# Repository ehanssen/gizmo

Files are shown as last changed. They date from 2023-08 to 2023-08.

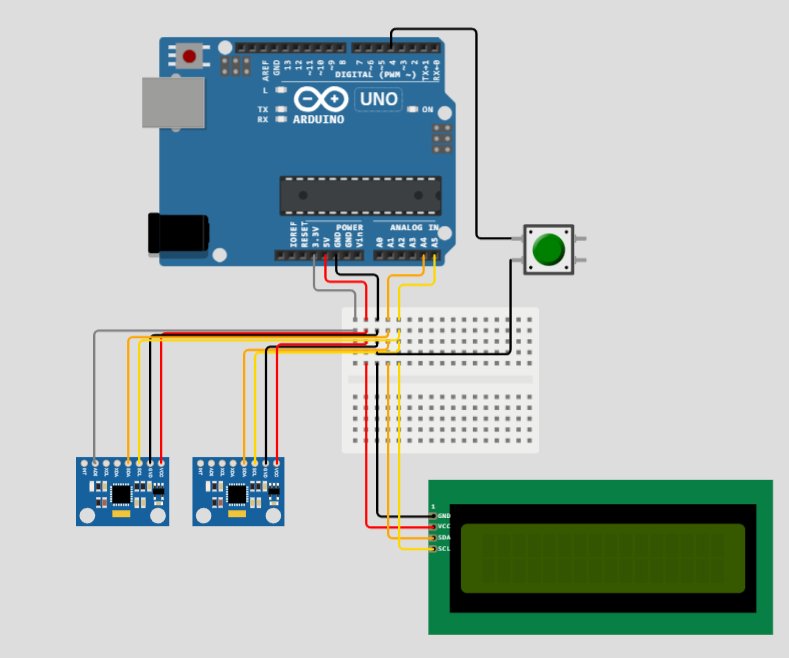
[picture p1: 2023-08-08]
wiring/wiring.jpg

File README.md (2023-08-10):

# Gizmo
A little tool to help read angles from ultramicrotomes. Works with https://github.com/automated-ultramicrotomy/crosshair

# Manual
- sample and knife at 0 degres
- start Gizmo and wait for a few seconds until values show on the LCD (usually 15-20sec)
- Press the button which will reset all values to 0 degres (+/- a small value)
- Set up CrossHair and record value
- Rotate the samples and knife by the offsets given by CrossHair
- All ROT, TLT and KNF drift a little overtime so make sure you add the offset more than the pure values
  (eg initial ROT was 4 degres, CrossHair ask for 6 degres but the original value of Gizmo slowly drifted to 4.6 degres while doing alignement and crosshair set up so set 6.6 degres) 

# Cite
Eric Hanssen and Phil Francis, Ian Holmes Imaging Centre, Bio21 Institute, the University of Melbourne.
[doi:10.5281/zenodo.8223274](https://doi.org/10.5281/zenodo.8223274)

# Note
Depending on your MPU6050 (and mainly where you get them from) you will likely have different readings. It is worth purchasing a few sensors and trying them all. Out of 6 sensors we origialy bought 2 where not working as they should and one was a not reliable.

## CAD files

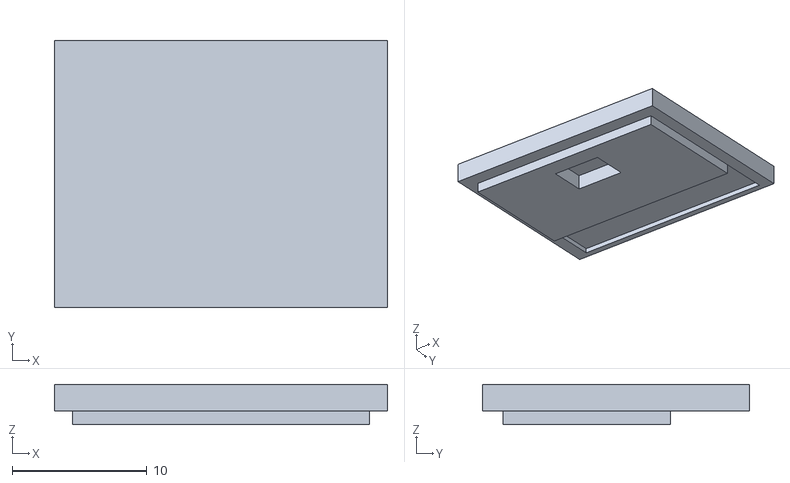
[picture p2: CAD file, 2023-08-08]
stl_files/top_MPU6050.stl
24.7 x 19.8 x 3.00

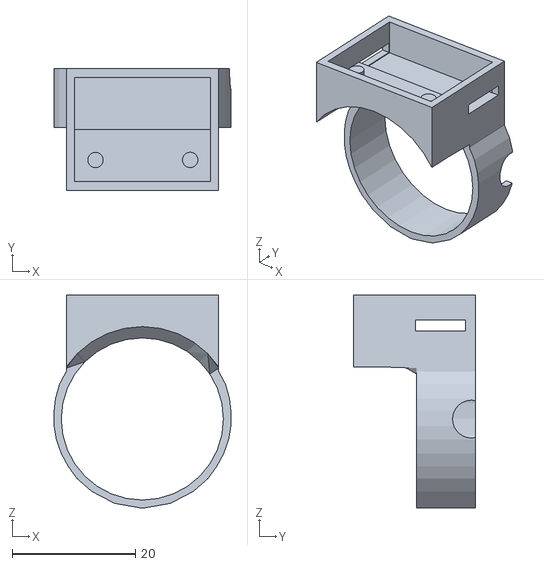
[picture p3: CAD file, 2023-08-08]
stl_files/sample_chuck_circle_MPU6050.stl
28.6 x 19.8 x 34.5

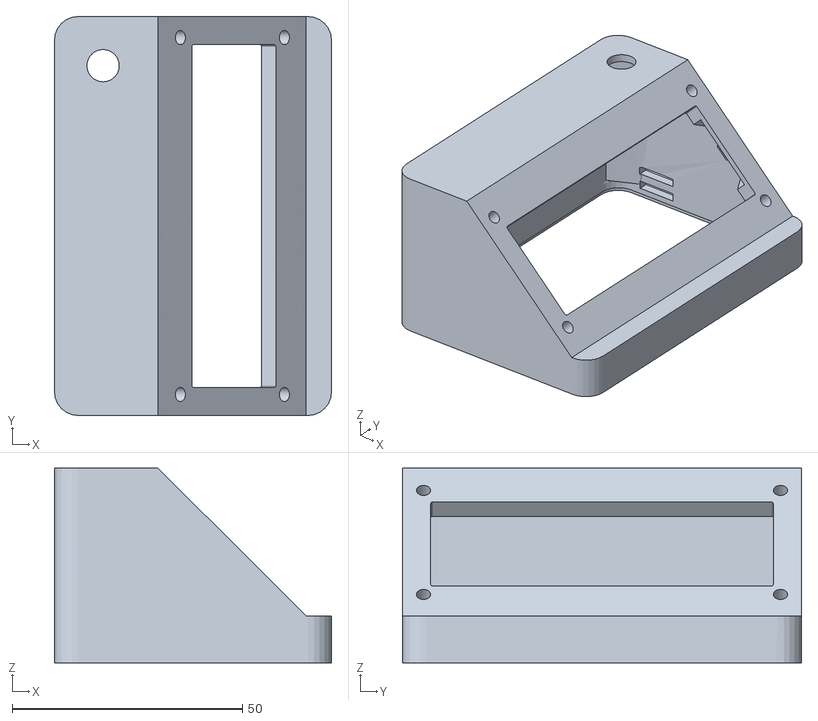
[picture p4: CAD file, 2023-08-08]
stl_files/arduino - box-top.stl
60.1 x 86.6 x 42.3

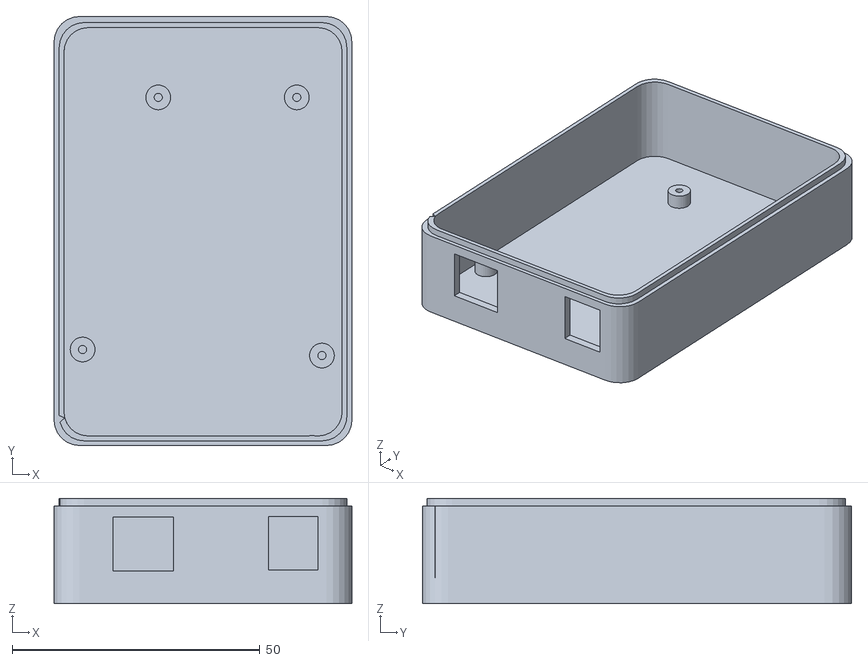
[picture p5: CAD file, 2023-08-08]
stl_files/arduino - box-bottom.stl
60.1 x 86.6 x 21.2

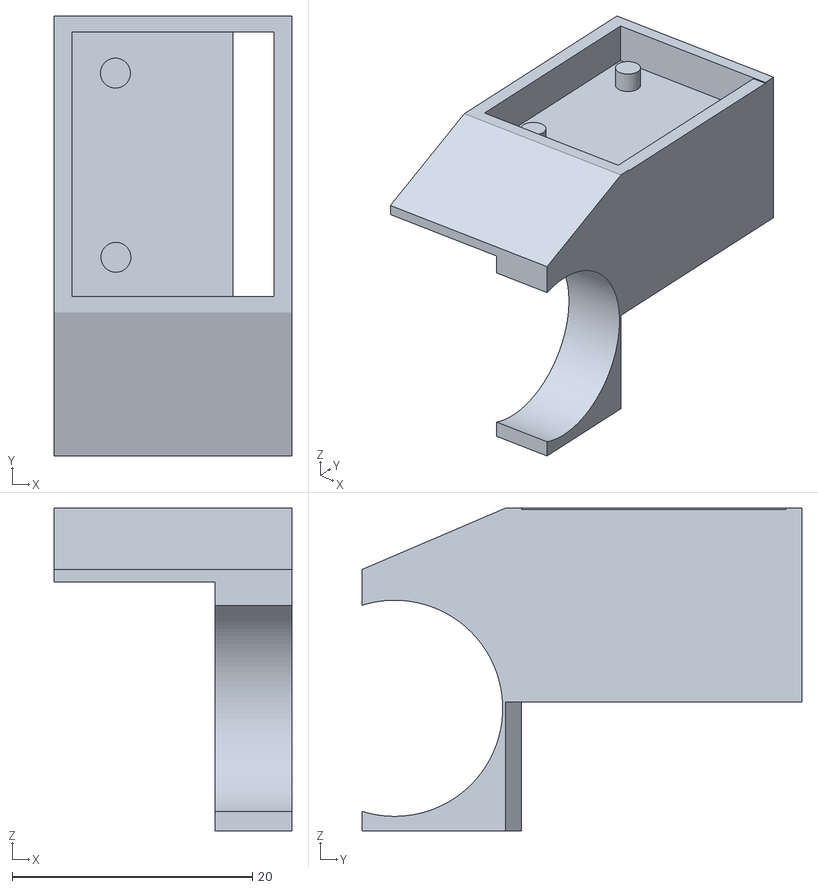
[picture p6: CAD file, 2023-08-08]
stl_files/knife_chuck_MPU6050.stl
19.8 x 36.7 x 26.9

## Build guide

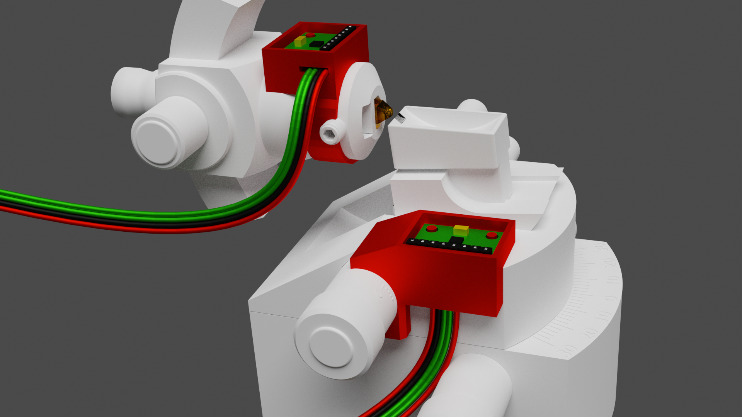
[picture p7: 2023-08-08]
stl_files/setup.png

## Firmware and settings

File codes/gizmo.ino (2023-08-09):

/*
   Arduino and 2 * MPU6050 Accelerometers for ultramicrotome angle reading
   very bad code (but works) from Eric Hanssen and Phil Francis inspired from https://howtomechatronics.com/tutorials/arduino/arduino-and-mpu6050-accelerometer-and-gyroscope-tutorial/
   Ian Holmes Imaging Centre, Bio21 Institute, The University of Melbourne, Australia
   Gizmo v1.1
*/

#include <Wire.h>
#include <LiquidCrystal_I2C.h>
#include <MPU605069_tockn.h>
#include <MPU6050_tockn.h>
LiquidCrystal_I2C lcd(0x27,16,2);  // set the LCD address to 0x27 for a 16 chars and 2 line display

MPU605069 mpu1(Wire); //MPU6050 on sample chuck
MPU6050 mpu2(Wire); // MPU6050 I2C addresses on knife block
long timer = 0;

//Pushbutton definition start

#define ResetPin 4

int lastButtonState=0;
int currentButtonState;

float zeroX1=0;
float zeroY1=0;
float zeroZ2=0;


 // MPU6050 I2C address
float AccX, AccY, AccZ, AccX2, AccY2,AccZ2;
float GyroX, GyroY, GyroZ, GyroX2, GyroY2, GyroZ2;
float accAngleX, accAngleY, gyroAngleX, gyroAngleY, gyroAngleZ, accAngleX2, accAngleY2, gyroAngleX2, gyroAngleY2, gyroAngleZ2;
float roll, pitch, yaw, roll2, pitch2, yaw2, x1,y1,z1,x2,y2,z2;
float AccErrorX, AccErrorY, GyroErrorX, GyroErrorY, GyroErrorZ;
float elapsedTime, currentTime, previousTime;
int c = 0;

void setup() {
  pinMode(ResetPin, INPUT_PULLUP);    // initialise PushButton
  
  lcd.init();                      // initialize the lcd 
  lcd.init();
  lcd.backlight();

  lcd.print("ROT");
  lcd.setCursor(12,0);
  lcd.print("TLT");
  lcd.setCursor(7,1);
  lcd.print("KNF");

  mpu1.begin();                      //MPU on 0x69 (sample)
  mpu1.calcGyroOffsets(true);
  mpu2.begin();                      //MPU on 0x68 (knife)
  mpu2.calcGyroOffsets(true);
}

//Reset button def starts
void ResetMPU6050(float x, float y, float z){
  //Center the Joystick at current position
  zeroX1=roll;
  zeroY1=pitch;
  zeroZ2=yaw2;
}
//Reset button def ends

void loop() {
 
  // === Read data === //
  //MPU1 sample
  mpu1.update();
  //MPU2 Knife
  mpu2.update();
   
  //=== calculate roll, pitch and yaw === //
  // Currently the raw values are in degrees per seconds, deg/s, so we need to multiply by seconds (s) to get the angle in degrees
  roll = mpu1.getGyroAngleX();
  pitch= mpu1.getGyroAngleY();
  yaw2 = mpu2.getGyroAngleZ();


  //define roll (Sample rotation), pitch (sample tilt) and yaw (knife rotation)
  roll = roll;
  pitch =pitch;
  yaw2=yaw2; //maybe remove

  //reset the values to zero on pressing Pushbutton
  if (!digitalRead(ResetPin)) {
  ResetMPU6050(roll,pitch,yaw);
  ResetMPU6050(roll2,pitch2,yaw2);
  }

  roll-=zeroX1;
  pitch-=zeroY1;
  yaw2-=zeroZ2;

	// Print a message to the LCD.
  
  lcd.setCursor(4,0);
  lcd.print(roll,1);
  
  lcd.setCursor(0,1);
  lcd.print(pitch,1);
  
  lcd.setCursor(11,1);
  lcd.print(yaw2,1);
  lcd.print("  ");

  //print angles to computer if needed
 /* Serial.print(" Xnorm = ");
  Serial.print(roll,1);
  Serial.print(" Ynorm = ");
  Serial.print(pitch,1);
  Serial.print(" Znorm = ");
  Serial.println(yaw2,1);*/

  delay(100);
}

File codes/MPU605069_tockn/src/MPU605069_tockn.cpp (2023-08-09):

#include "MPU605069_tockn.h"
#include "Arduino.h"

MPU605069::MPU605069(TwoWire &w){
  wire = &w;
  accCoef = 0.02f;
  gyroCoef = 0.98f;
}

MPU605069::MPU605069(TwoWire &w, float aC, float gC){
  wire = &w;
  accCoef = aC;
  gyroCoef = gC;
}

void MPU605069::begin(){
  writeMPU605069(MPU605069_SMPLRT_DIV, 0x00);
  writeMPU605069(MPU605069_CONFIG, 0x00);
  writeMPU605069(MPU605069_GYRO_CONFIG, 0x08);
  writeMPU605069(MPU605069_ACCEL_CONFIG, 0x00);
  writeMPU605069(MPU605069_PWR_MGMT_1, 0x01);
  this->update();
  angleGyroX = 0;
  angleGyroY = 0;
  angleX = this->getAccAngleX();
  angleY = this->getAccAngleY();
  preInterval = millis();
}

void MPU605069::writeMPU605069(byte reg, byte data){
  wire->beginTransmission(MPU605069_ADDR);
  wire->write(reg);
  wire->write(data);
  wire->endTransmission();
}

byte MPU605069::readMPU605069(byte reg) {
  wire->beginTransmission(MPU605069_ADDR);
  wire->write(reg);
  wire->endTransmission(true);
  wire->requestFrom(MPU605069_ADDR, 1);
  byte data =  wire->read();
  return data;
}

void MPU605069::setGyroOffsets(float x, float y, float z){
  gyroXoffset = x;
  gyroYoffset = y;
  gyroZoffset = z;
}

void MPU605069::calcGyroOffsets(bool console, uint16_t delayBefore, uint16_t delayAfter){
	float x = 0, y = 0, z = 0;
	int16_t rx, ry, rz;

  delay(delayBefore);
	if(console){
    Serial.println();
    Serial.println("========================================");
    Serial.println("Calculating gyro offsets");
    Serial.print("DO NOT MOVE MPU605069");
  }
  for(int i = 0; i < 3000; i++){
    if(console && i % 1000 == 0){
      Serial.print(".");
    }
    wire->beginTransmission(MPU605069_ADDR);
    wire->write(0x43);
    wire->endTransmission(false);
    wire->requestFrom((int)MPU605069_ADDR, 6);

    rx = wire->read() << 8 | wire->read();
    ry = wire->read() << 8 | wire->read();
    rz = wire->read() << 8 | wire->read();

    x += ((float)rx) / 65.5;
    y += ((float)ry) / 65.5;
    z += ((float)rz) / 65.5;
  }
  gyroXoffset = x / 3000;
  gyroYoffset = y / 3000;
  gyroZoffset = z / 3000;

  if(console){
    Serial.println();
    Serial.println("Done!");
    Serial.print("X : ");Serial.println(gyroXoffset);
    Serial.print("Y : ");Serial.println(gyroYoffset);
    Serial.print("Z : ");Serial.println(gyroZoffset);
    Serial.println("Program will start after 3 seconds");
    Serial.print("========================================");
		delay(delayAfter);
	}
}

void MPU605069::update(){
	wire->beginTransmission(MPU605069_ADDR);
	wire->write(0x3B);
	wire->endTransmission(false);
	wire->requestFrom((int)MPU605069_ADDR, 14);

  rawAccX = wire->read() << 8 | wire->read();
  rawAccY = wire->read() << 8 | wire->read();
  rawAccZ = wire->read() << 8 | wire->read();
  rawTemp = wire->read() << 8 | wire->read();
  rawGyroX = wire->read() << 8 | wire->read();
  rawGyroY = wire->read() << 8 | wire->read();
  rawGyroZ = wire->read() << 8 | wire->read();

  temp = (rawTemp + 12412.0) / 340.0;

  accX = ((float)rawAccX) / 16384.0;
  accY = ((float)rawAccY) / 16384.0;
  accZ = ((float)rawAccZ) / 16384.0;

  angleAccX = atan2(accY, accZ + abs(accX)) * 360 / 2.0 / PI;
  angleAccY = atan2(accX, accZ + abs(accY)) * 360 / -2.0 / PI;

  gyroX = ((float)rawGyroX) / 65.5;
  gyroY = ((float)rawGyroY) / 65.5;
  gyroZ = ((float)rawGyroZ) / 65.5;

  gyroX -= gyroXoffset;
  gyroY -= gyroYoffset;
  gyroZ -= gyroZoffset;

  interval = (millis() - preInterval) * 0.001;

  angleGyroX += gyroX * interval;
  angleGyroY += gyroY * interval;
  angleGyroZ += gyroZ * interval;

  angleX = (gyroCoef * (angleX + gyroX * interval)) + (accCoef * angleAccX);
  angleY = (gyroCoef * (angleY + gyroY * interval)) + (accCoef * angleAccY);
  angleZ = angleGyroZ;

  preInterval = millis();

}
